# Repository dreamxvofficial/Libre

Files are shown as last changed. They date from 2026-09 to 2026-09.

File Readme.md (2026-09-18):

# Libre By DreamXV #
## It is an E-Ink Reading Device made for portability and mostly for warm-up week of *halflife.hackclub.com*. I have always been a fan of Kindle but its price is too high and it is not that customizable so I thought of making my own e-ink reader. ##
---
## Specs ##
- **Processor** ESP32-S3-WROOM-1-N16R8
- **Display** Waveshare 4.2", 400×300, B/W, SPI
- **Battery** 3.7 V Li-Po, 2000 mAh
- **MicroSD card**	16/32 GB 
- **USB-C** USB 2.0 Type-C receptacle
- **5 UI buttons** 6×6 × ~5 mm tactile push button
- **Power switch** SPDT slide switch

## Inspo Look ##
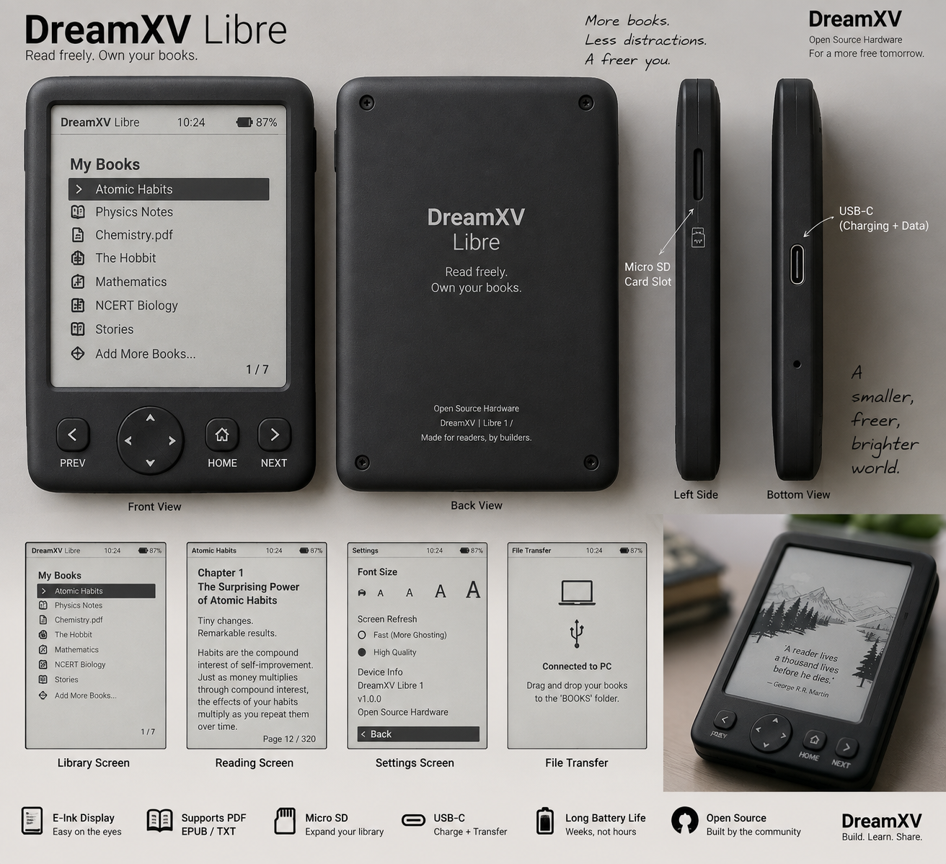
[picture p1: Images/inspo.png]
Inspo Look


## Approximate BOM : ##

| Part | Specification | Qty |
| --- | --- | --: |
| E-Ink Display | Waveshare 4.2" 400×300 B/W, SPI | 1 |
| Microcontroller | ESP32-S3-DevKitC-1-N16R8V | 1 |
| Storage | 16–32GB MicroSD Card + Socket | 1 |
| Battery | 3.7V 3000mAh Li-Po | 1 |
| Charging | MCP73831 Li-Po Charging Circuit | 1 |
| Power Switch | SPDT ON/OFF Slide Switch | 1 |
| Navigation | 6×6mm SMD Tactile Buttons | 5 |
| PCB | Custom 2-Layer PCB | 1 |
| Enclosure | Custom 3D-Printed Case | 1 |

## ** Approximate BOM ~ $110 or ~₹10,500 INR ** ##

## Schematic ##
### So i used AI for planing the connections of schematics and it just made me wanna die so yeah i dont know what to write more but i have connected the screen mcu micro sd and buttons together i dont know how but yes i have connected ###

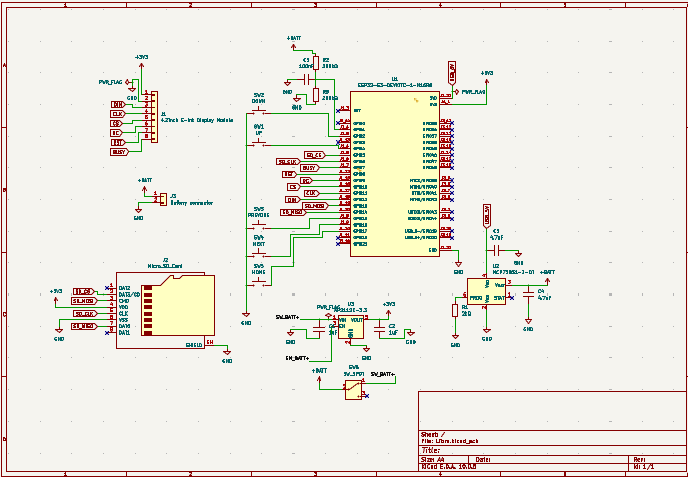
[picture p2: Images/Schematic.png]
Schematic


## PCB ## 
### I just wanna give up mannnnnnnnnnn! >>>>>>>>>>3 I had to change the whole design as PCB was not as size of CAD so here is the new PCB with MCU ESP 32, 5 buttons 1 slider button and Micro SD Card ##
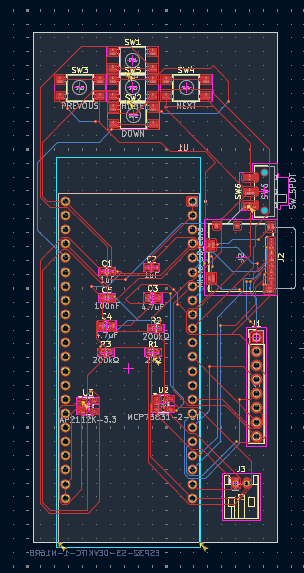
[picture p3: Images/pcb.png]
PCB

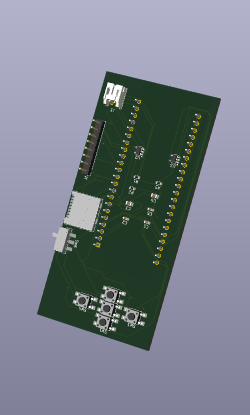
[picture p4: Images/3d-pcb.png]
3D PCB


## CAD ##
### CAD design for Libre. It is 130 mm height and 78.5 mm width with a space for PCB, Buttons and E-Ink Display ##

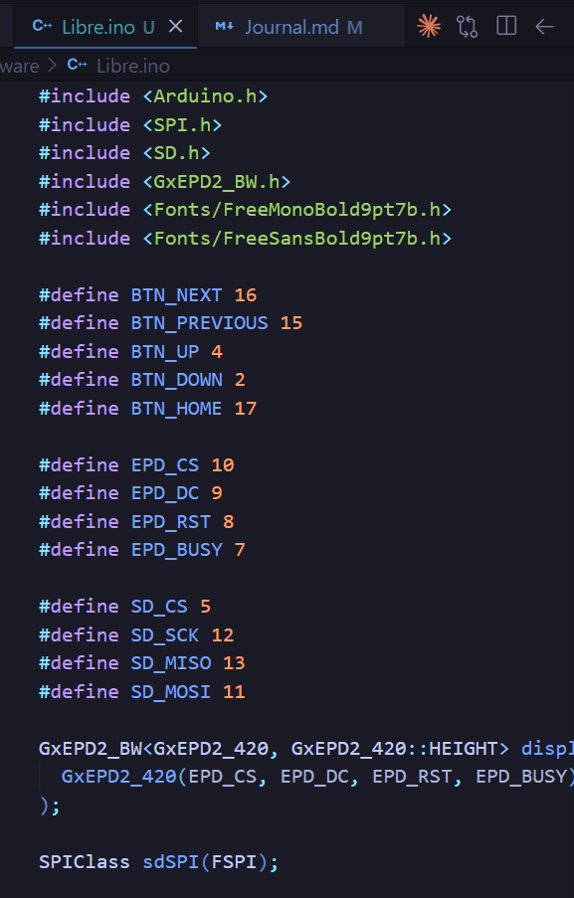
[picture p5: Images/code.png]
NewCAD


## Final BOM ##

# DreamXV Libre — Final BOM

| Part | Qty | Unit Price (INR) | Total (INR) | Price Basis | Design Ref |
|---|---:|---:|---:|---|---|
| Waveshare 4.2-inch E-Ink Module B, 400x300 | 1 | ₹4,861.00 | ₹4,861.00 | Amazon India / current listing checked | Main display |
| ESP32-S3-DEVKITC-1-N16R8V | 1 | ₹1,500.00 | ₹1,500.00 | Indian/Amazon market listing checked | Main MCU board |
| Li-Po battery 3.7V 3000mAh | 1 | ₹500.00 | ₹500.00 | Indian hobby-retailer budget | Battery |
| Custom PCB | 1 | ₹1,000.00 | ₹1,000.00 | User budget | PCB fabrication |
| 3D-printed enclosure | 1 | ₹960.00 | ₹960.00 | User budget: $10 | 3D printing |
| Molex 104031-0811 MicroSD socket | 1 | ₹100.00 | ₹100.00 | Indian distributor budget | J2 |
| JST-PH 2-pin battery connector | 1 | ₹40.00 | ₹40.00 | Indian hobby-retailer budget | J3 |
| 8-pin display connector/header | 1 | ₹50.00 | ₹50.00 | Indian hobby-retailer budget | J1 |
| MCP73831-2-OT Li-Po charger IC | 1 | ₹80.00 | ₹80.00 | Indian distributor budget | U2 |
| AP2112K-3.3 LDO | 1 | ₹50.00 | ₹50.00 | Indian distributor budget | U3 |
| TL3305AF160QG SMD tactile button | 5 | ₹48.00 | ₹240.00 | Robu India listing | SW1-SW5 |
| C&K JS102011SAQN SPDT SMD switch | 1 | ₹150.00 | ₹150.00 | Indian distributor budget | SW6 |
| 1uF 0805 MLCC | 2 | ₹10.00 | ₹20.00 | Robu India example | C1-C2 |
| 4.7uF MLCC | 2 | ₹15.00 | ₹30.00 | Indian distributor budget | C3-C4 |
| 100nF 0805 MLCC | 1 | ₹3.00 | ₹3.00 | Indian distributor budget | C5 |
| 2kΩ 0805 resistor | 1 | ₹2.00 | ₹2.00 | Indian distributor budget | R1 |
| 200kΩ 0805 resistor | 2 | ₹0.31 | ₹0.62 | Robu India example | R2-R3 |

## Total Cost

- **Total INR:** ₹9,586.62
- **Exchange Rate:** ₹95.95 = $1
- **Total USD:** $99.91
- **Budget:** $100
- **Status:** UNDER $100

## Firmware ##

### ** The firmware is written for the ESP32-S3 and handles the main functions of Libre like the E-Ink display, MicroSD card, 5 navigation buttons and battery monitoring. It also has a simple file browser for selecting books and basic TXT reading. PDF files can be detected and listed, with proper PDF rendering planned for a future version. ** ###

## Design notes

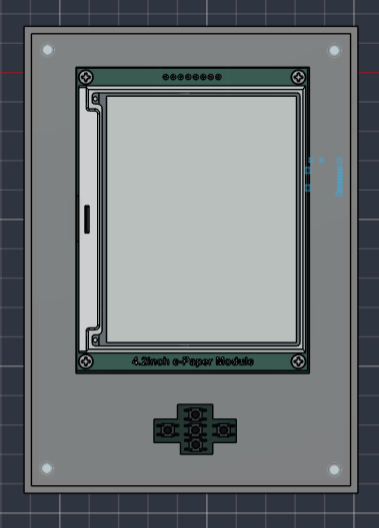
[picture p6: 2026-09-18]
Images/NewCAD.png

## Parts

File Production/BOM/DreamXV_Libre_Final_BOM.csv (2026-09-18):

Part | Specification | Qty | Total Price INR
E-Ink Display | Waveshare 4.2 inch, 400x300, SPI | 1 | 4861.18
MCU | ESP32-S3-DevKitC-1-N16R8V | 1 | 1500.00
Battery | 3.7V 3000mAh Li-Po | 1 | 469.00
Custom PCB | 2-layer PCB | 1 | 1000.00
3D Printed Enclosure | Custom CAD enclosure | 1 | 1920.00
MicroSD Socket | Molex 104031-0811 | 1 | 100.00
JST Battery Connector | JST-PH 2-pin | 1 | 40.00
Display Header | 1x8, 2.54mm | 1 | 50.00
Li-Po Charger | MCP73831-2-OT | 1 | 80.00
3.3V LDO | AP2112K-3.3 | 1 | 50.00
Navigation Buttons | 6x6mm SMD tactile | 5 | 240.00
Power Switch | C&K JS102011SAQN SPDT | 1 | 115.00
1uF Capacitors | 0805 MLCC | 2 | 20.00
4.7uF Capacitors | MLCC | 2 | 30.00
100nF Capacitor | 0805 | 1 | 3.00
2kΩ Resistor | 0805 | 1 | 2.00
200kΩ Resistors | 0805 | 2 | 0.62
TOTAL

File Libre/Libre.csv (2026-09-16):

Reference | Qty | Value | DNP | Exclude from BOM | Exclude from Board | Exclude from Simulation | Exclude from Position Files | Footprint | Datasheet
C1,C2 | 2 | 1uF |  |  |  |  | ${EXCLUDE_FROM_POS_FILES} | Capacitor_SMD:C_0603_1608Metric
C3,C4 | 2 | 4.7uF |  |  |  |  | ${EXCLUDE_FROM_POS_FILES} | Capacitor_SMD:C_0805_2012Metric
C5 | 1 | 100nF |  |  |  |  | ${EXCLUDE_FROM_POS_FILES} | Capacitor_SMD:C_0603_1608Metric
J1 | 1 | 4.2inch E-Ink Display Module |  |  |  |  | ${EXCLUDE_FROM_POS_FILES} | Connector_PinHeader_2.54mm:PinHeader_1x08_P2.54mm_Vertical
J2 | 1 | Micro_SD_Card |  |  |  |  | ${EXCLUDE_FROM_POS_FILES} | Connector_Card:microSD_HC_Molex_104031-0811 | https://www.we-online.com/components/products/datasheet/693072010801.pdf
J3 | 1 | Battery connector |  |  |  |  | ${EXCLUDE_FROM_POS_FILES} | Connector_JST:JST_PH_S2B-PH-K_1x02_P2.00mm_Horizontal
R1 | 1 | 2kΩ |  |  |  |  | ${EXCLUDE_FROM_POS_FILES} | Resistor_SMD:R_0603_1608Metric
R2,R3 | 2 | 200kΩ |  |  |  |  | ${EXCLUDE_FROM_POS_FILES} | Resistor_SMD:R_0603_1608Metric
SW1 | 1 | UP |  |  |  |  | ${EXCLUDE_FROM_POS_FILES} | Button_Switch_SMD:SW_SPST_TL3305A
SW2 | 1 | DOWN |  |  |  |  | ${EXCLUDE_FROM_POS_FILES} | Button_Switch_SMD:SW_SPST_TL3305A
SW3 | 1 | PREVOUS |  |  |  |  | ${EXCLUDE_FROM_POS_FILES} | Button_Switch_SMD:SW_SPST_TL3305A
SW4 | 1 | NEXT |  |  |  |  | ${EXCLUDE_FROM_POS_FILES} | Button_Switch_SMD:SW_SPST_TL3305A
SW5 | 1 | HOME |  |  |  |  | ${EXCLUDE_FROM_POS_FILES} | Button_Switch_SMD:SW_SPST_TL3305A
SW6 | 1 | SW_SPDT |  |  |  |  | ${EXCLUDE_FROM_POS_FILES} | Button_Switch_SMD:SW_SPDT_CK_JS102011SAQN
U1 | 1 | ESP32-S3-DEVKITC-1-N16R8 |  |  |  |  | ${EXCLUDE_FROM_POS_FILES} | Esp:XCVR_ESP32-S3-DEVKITC-1-N16R8V
U2 | 1 | MCP73831-2-OT |  |  |  |  | ${EXCLUDE_FROM_POS_FILES} | Package_TO_SOT_SMD:SOT-23-5 | http://ww1.microchip.com/downloads/en/DeviceDoc/20001984g.pdf
U3 | 1 | AP2112K-3.3 |  |  |  |  | ${EXCLUDE_FROM_POS_FILES} | Package_TO_SOT_SMD:SOT-23-5 | https://www.diodes.com/assets/Datasheets/AP2112.pdf

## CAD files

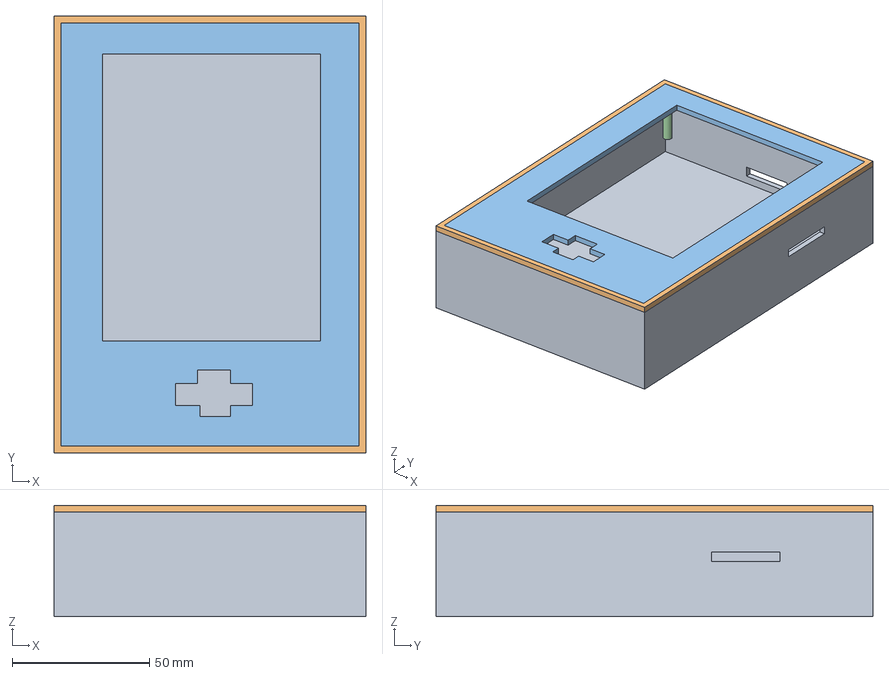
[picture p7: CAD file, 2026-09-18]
Production/CAD_Case/Libre_PCB_Assembly.step
113.5 x 159.0 x 40.5 mm

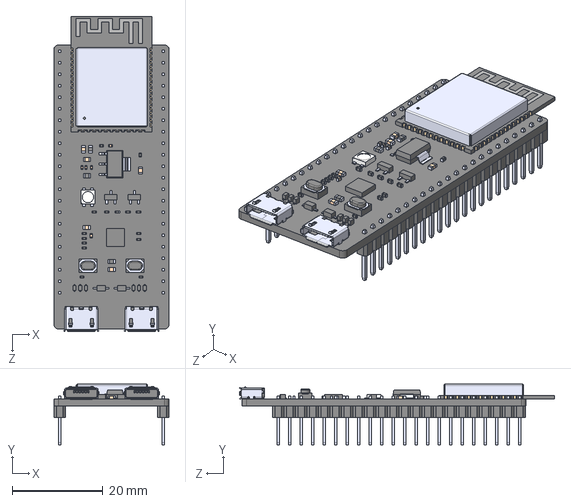
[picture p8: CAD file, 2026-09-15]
Additional Models and Schematics/ESP32-S3-DEVKITC-1-N16R8V/ESP32-S3-DEVKITC-1-N16R8V.step
25.4 x 13.4 x 69.6 mm

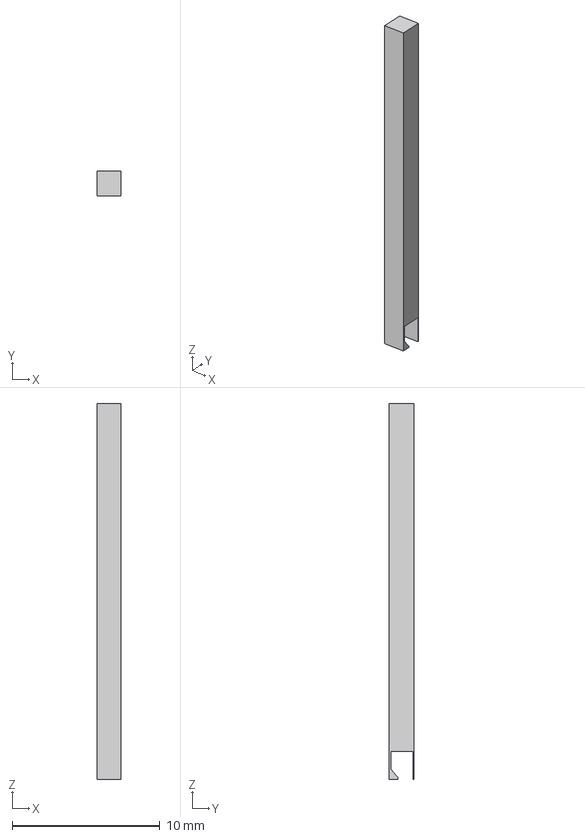
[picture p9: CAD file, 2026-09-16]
Additional Models and Schematics/Slider Cap.step
1.65 x 1.70 x 25.4 mm

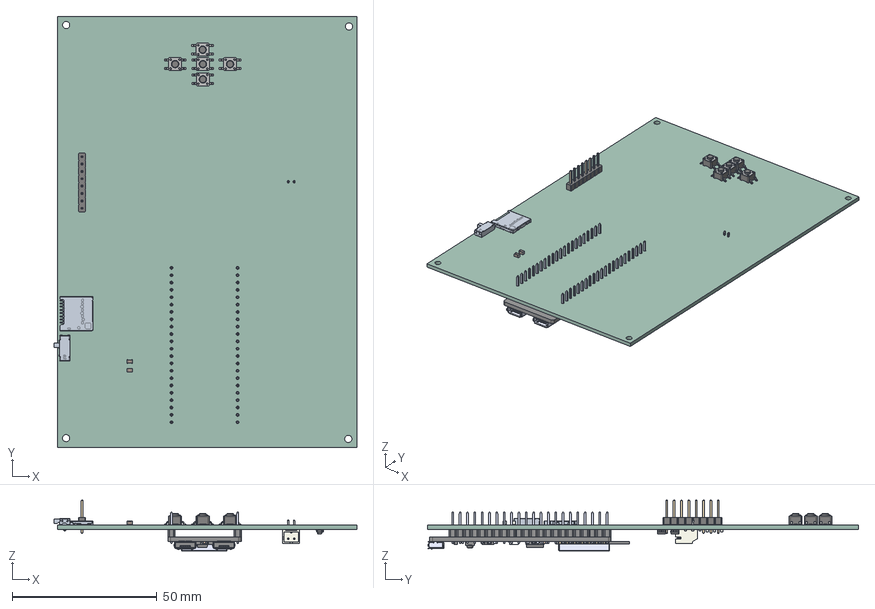
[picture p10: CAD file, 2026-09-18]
Libre/Libre.step
104.7 x 149.0 x 17.6 mm
SW_SPST_TL3305A x 5
C_0805_2012Metric x 2
PinHeader_1x08_P254mm_Vertical
JS102011SAQN_SW0004_PRT
ESP32-S3-DEVKITC-1-N8R2
SOT-23-5 x 2
C_0603_1608Metric x 3
R_0603_1608Metric x 3
JST_S2B_PH_K
Libre_PCB

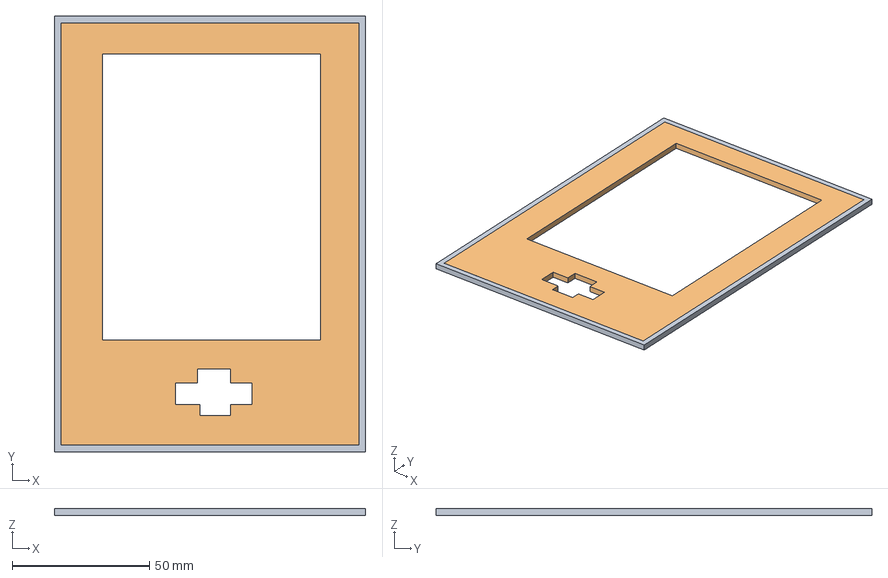
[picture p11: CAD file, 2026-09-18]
Production/CAD_Case/Libre_PCB_Lid.step
113.5 x 159.0 x 2.50 mm

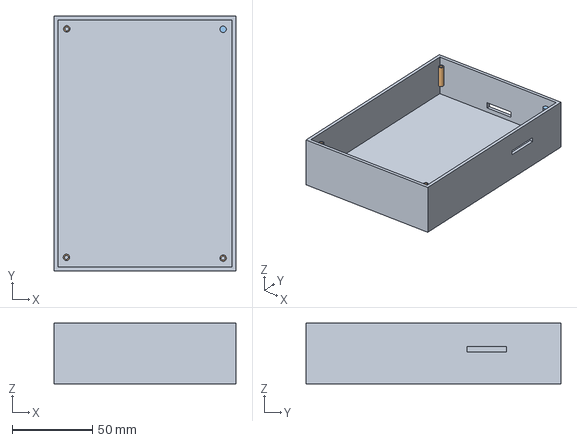
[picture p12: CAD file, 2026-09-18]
Production/CAD_Case/Libre_PCB_Base.step
113.5 x 159.0 x 38.0 mm

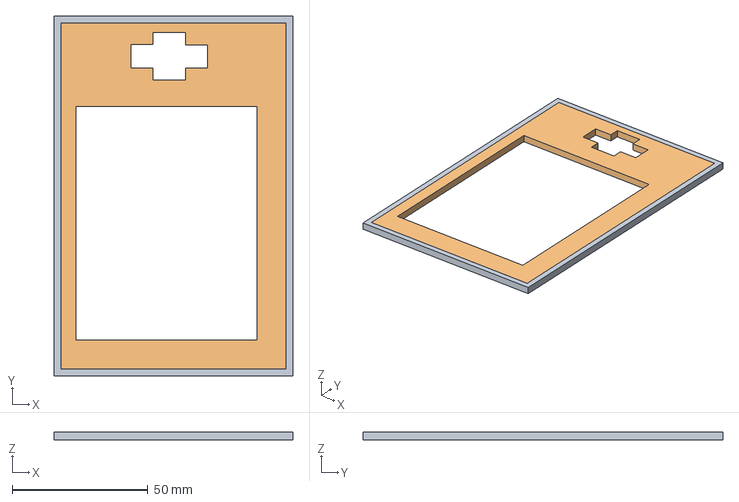
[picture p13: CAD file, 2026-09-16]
Production/CAD_Case/Libre_LID.step
87.8 x 132.5 x 3.00 mm

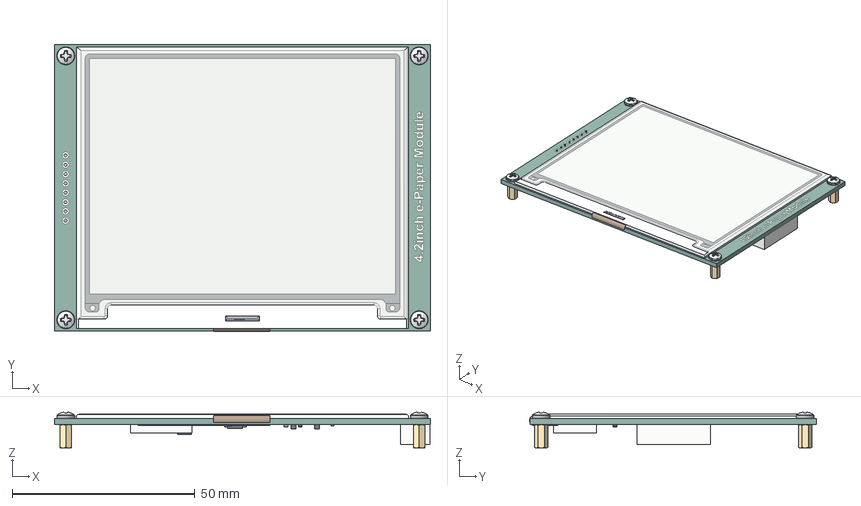
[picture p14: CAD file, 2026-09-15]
Additional Models and Schematics/Waveshare 4.2inch e-Paper Module.step
103.0 x 78.6 x 9.79 mm
Waveshare 4.2 E-Ink - Display folded cable
PCB
90268A201 x 4
91772A030 x 4

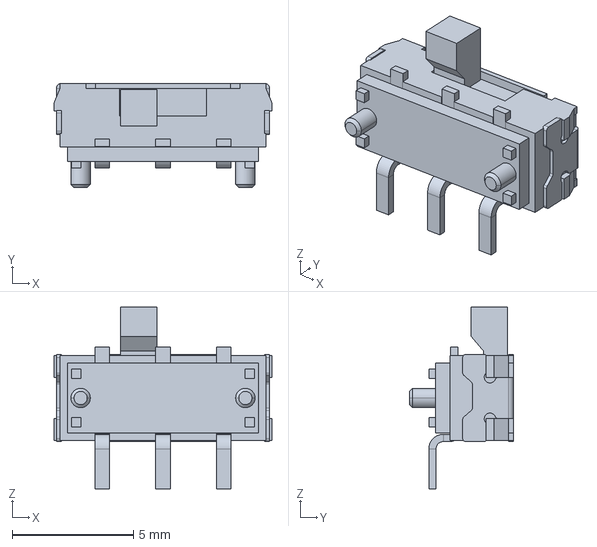
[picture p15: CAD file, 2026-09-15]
Additional Models and Schematics/JS102011SAQN.step
9.00 x 4.30 x 7.50 mm

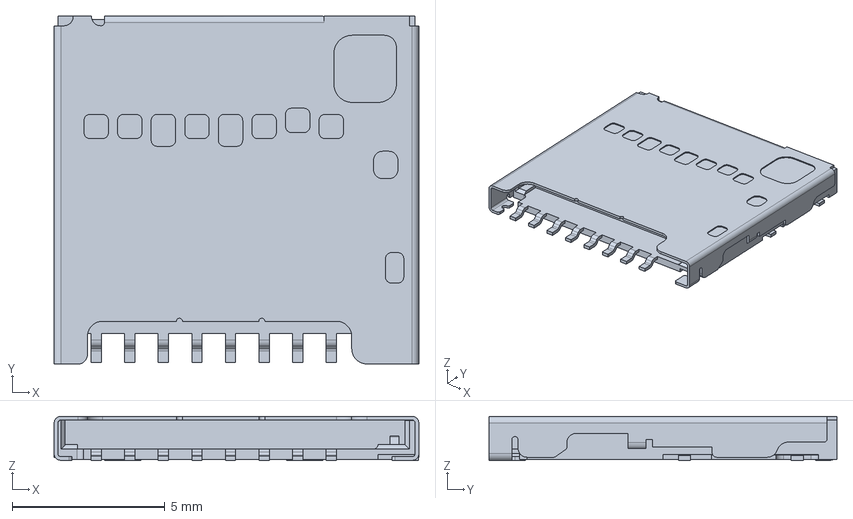
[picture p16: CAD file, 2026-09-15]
Additional Models and Schematics/1040310811.stp
11.9 x 11.4 x 1.45 mm

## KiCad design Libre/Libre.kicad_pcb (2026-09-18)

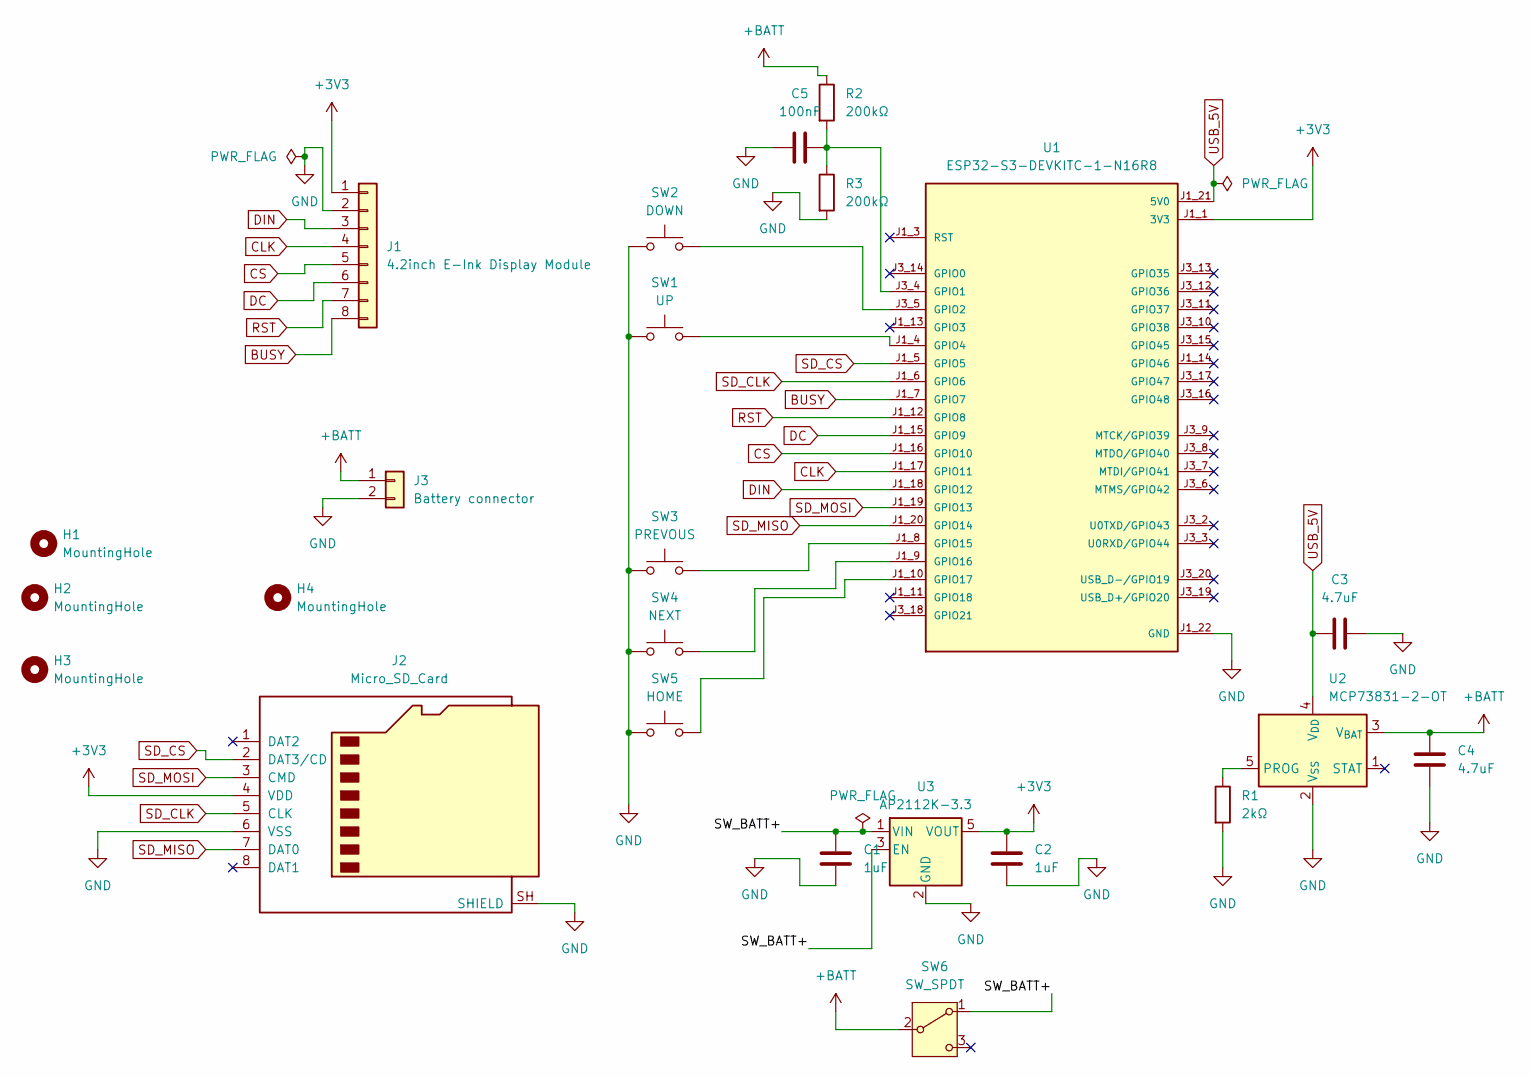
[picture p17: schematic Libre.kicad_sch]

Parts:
C1, C2: 1uF; C_0603_1608Metric
C3, C4: 4.7uF; C_0805_2012Metric
C5: 100nF; C_0603_1608Metric
H1, H2, H3, H4: MountingHole; MountingHole_2.5mm
J1: 4.2inch E-Ink Display Module; PinHeader_1x08_P2.54mm_Vertical
J2: Micro_SD_Card; microSD_HC_Molex_104031-0811
J3: Battery connector; JST_PH_S2B-PH-K_1x02_P2.00mm_Horizontal
R1: 2kΩ; R_0603_1608Metric
R2, R3: 200kΩ; R_0603_1608Metric
SW1: UP; SW_SPST_TL3305A
SW2: DOWN; SW_SPST_TL3305A
SW3: PREVOUS; SW_SPST_TL3305A
SW4: NEXT; SW_SPST_TL3305A
SW5: HOME; SW_SPST_TL3305A
SW6: SW_SPDT; SW_SPDT_CK_JS102011SAQN
U1: ESP32-S3-DEVKITC-1-N16R8; XCVR_ESP32-S3-DEVKITC-1-N16R8V; PARTREV V1
U2: MCP73831-2-OT; SOT-23-5
U3: AP2112K-3.3; SOT-23-5

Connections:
+3V3: C2.1, J1.1, J2.4 (VDD), U1.J1_1 (3V3), U1.J1_2 (3V3), U3.5 (VOUT)
+BATT: C4.1, J3.1, R2.1, SW6.2 (B), U2.3 (V_{BAT})
/SW_BATT+: C1.1, SW6.1 (A), U3.1 (VIN), U3.3 (EN)
BUSY: J1.8, U1.J1_7 (GPIO7)
CLK: J1.4, U1.J1_17 (GPIO11)
CS: J1.5, U1.J1_16 (GPIO10)
DC: J1.6, U1.J1_15 (GPIO9)
DIN: J1.3, U1.J1_18 (GPIO12)
GND: C1.2, C2.2, C3.2, C4.2, C5.1, J1.2, J2.6 (VSS), J2.SH (SHIELD), J3.2, R1.2, R3.2, SW1.1, SW2.1, SW3.1, SW4.1, SW5.1, U1.J1_22 (GND), U1.J3_1 (GND), U1.J3_21 (GND), U1.J3_22 (GND), U2.2 (V_{SS}), U3.2 (GND)
unnamed: C5.2, R2.2, R3.1, U1.J3_4 (GPIO1)
unnamed: SW2.2, U1.J3_5 (GPIO2)
unnamed: SW1.2, U1.J1_4 (GPIO4)
unnamed: SW3.2, U1.J1_8 (GPIO15)
unnamed: SW4.2, U1.J1_9 (GPIO16)
unnamed: SW5.2, U1.J1_10 (GPIO17)
unnamed: R1.1, U2.5 (PROG)
RST: J1.7, U1.J1_12 (GPIO8)
SD_CLK: J2.5 (CLK), U1.J1_6 (GPIO6)
SD_CS: J2.2 (DAT3/CD), U1.J1_5 (GPIO5)
SD_MISO: J2.7 (DAT0), U1.J1_20 (GPIO14)
SD_MOSI: J2.3 (CMD), U1.J1_19 (GPIO13)
USB_5V: C3.1, U1.J1_21 (5V0), U2.4 (V_{DD})

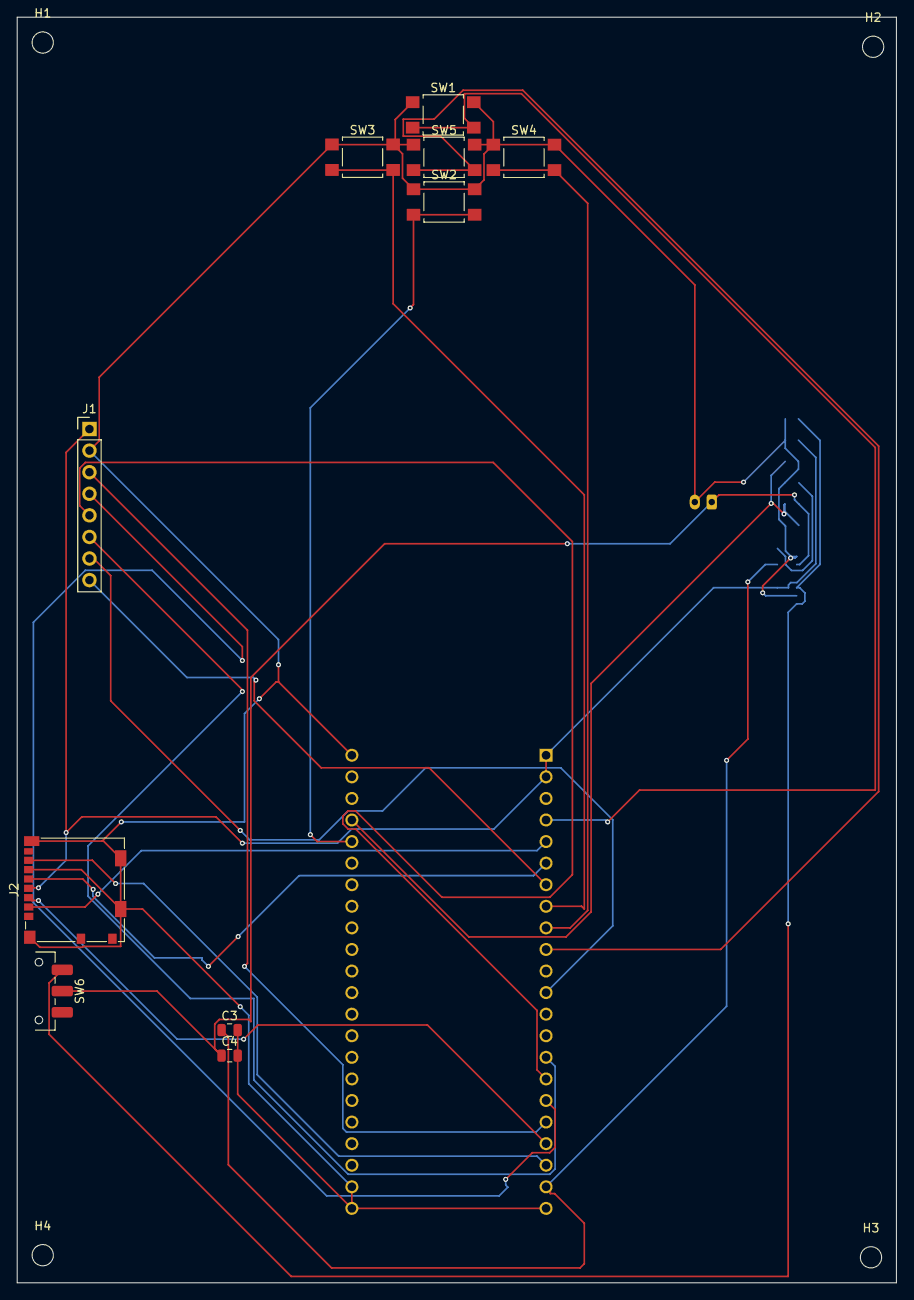
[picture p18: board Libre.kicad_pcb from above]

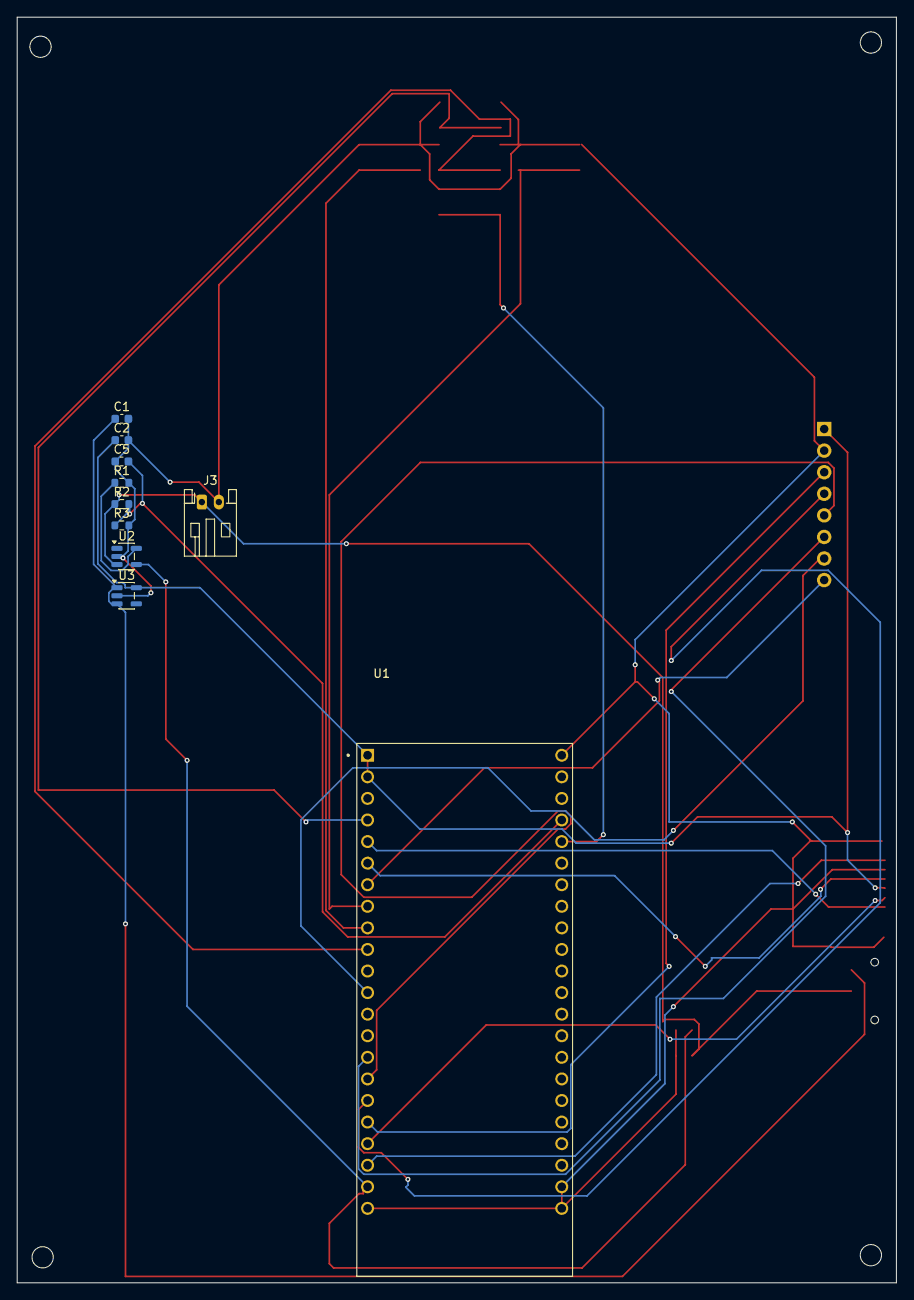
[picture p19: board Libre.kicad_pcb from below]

Board: 2 copper layers, 103.5 x 149.0 mm, 24 parts (10 on the bottom side), 22 nets.

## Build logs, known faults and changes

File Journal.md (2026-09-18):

# Libre by DreamXV #
## I will be documenting this project in journal as well as lapse and hacktime##
---
## Day 1 - 14 sept 26 ##
### So from today warm-up wek started and i thought of making a e-ink reader for myself which i can use for reading like PDFs, ePUBs, Webtoons and other reading material. My main inspo is the amazon kindle so I have planned the following features for my reader:
- E-ink display
- Next Page Button
- Previous Page Button
- Up Button
- Down Button 
- And at last Home Button 

* Inspo Look of how it would look like *

Inspo Look

## Hardware ## 
### for now i have finalized the hardware list and it is available in Readme.md ### 

## For today i am only journaling as it is much of a brainstorming phase and i am yet to build Schematic PCB or CAD ##

## Time spent this session: 1 hour ##

---

## Day 2 - 15 sept 26 ##
## Session-1 ##
### So In this session I will be working on building schematic for Libre. So i used AI to help me make schematics and find sch and mod files for symbols and footprint. SO it took so much time and effort of mine to check and connect each gpio and pin properly. I also added micro sd card slot and all. Now going for lunch break.### 

Schematic
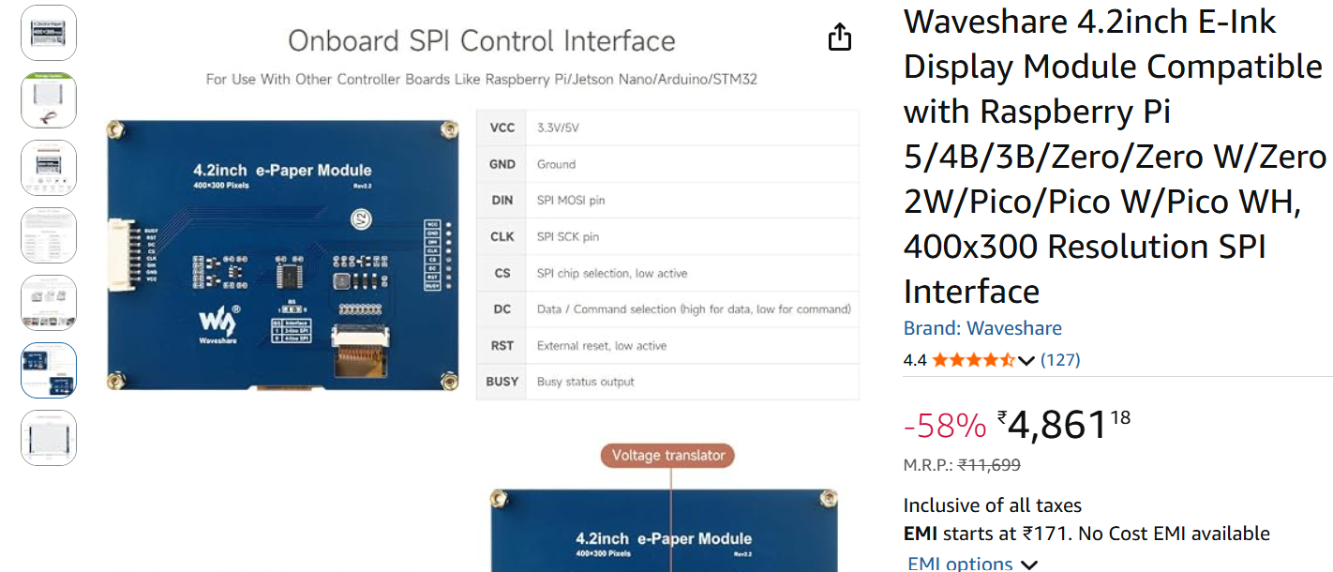
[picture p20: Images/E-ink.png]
Amazon Screen


## Time spent this session: 1 hour 40 mins  ##

## Day 2 - 15 sept 26 ##
## Session-2 ##
### So In this session I will be working on PCB design for Libre. It was hell lot worse then schematic to find step models and designing PCB according to display was nightmare. But finally I made it!... I just want to thank god to give me strength from making this pcb as i would have left the chat gng :3 .... Here i present you PCB ###
PCB
3D PCB

## Time spent this session: 2 Hours ##

## Day 2 - 15 sept 26 ##
## Session-3 ##
### So In this session I will be working on CAD design for Libre. It was the biggest mistake i made ever and because of it i had to make button and slider buttons extras so that it could be outside the frame to use but it turned out good for reading so now i present you CAD Design ### 

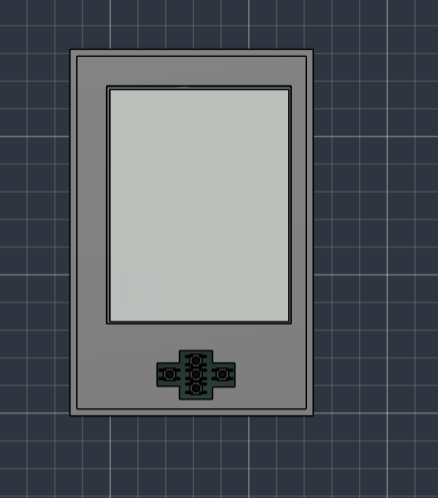
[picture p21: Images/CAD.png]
CAD


## Time spent this session: 1 Hour 56 Minutes ##

## Day 3 - 16 sept 26 ##
## Session-1 ##
### So In this session made final touches of cad design for button and it turned out good so here is the extra part for mounting buttons and slider ### 

Button Mount
Slider Mount

## Time spent this session: 12 Minutes ##

## Day 3 - 16 sept 26 ##
## Session-2 ##
### So In this session i wrote the firmware for Libre. So i wrote an os type system for it to select the pdf of the book in and read it . It was hell lot of fun and also challenging to write it as it was my first time writing firmware for an e-reader. But due to my C++ skill i coded it a lot faster. Butt i want to add more featuresas they are left. ### 

code

## Time spent this session: 43 Minutes ##

## Day 4 - 17 sept 26 ##
## Session-1 ##
### So In this session i remade the CAD as there were problems with previous CAD and had to make buttons caps as another thing but this time i fixed the pcb and made nice looking CAD and this would be the last journaling i think ##

PCB

## Time spent this session: 1hour 34 Minutes ##

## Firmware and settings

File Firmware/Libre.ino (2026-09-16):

#include <Arduino.h>
#include <SPI.h>
#include <SD.h>
#include <GxEPD2_BW.h>
#include <Fonts/FreeMonoBold9pt7b.h>
#include <Fonts/FreeSansBold9pt7b.h>

#define BTN_NEXT 16
#define BTN_PREVIOUS 15
#define BTN_UP 4
#define BTN_DOWN 2
#define BTN_HOME 17

#define EPD_CS 10
#define EPD_DC 9
#define EPD_RST 8
#define EPD_BUSY 7

#define SD_CS 5
#define SD_SCK 12
#define SD_MISO 13
#define SD_MOSI 11

GxEPD2_BW<GxEPD2_420, GxEPD2_420::HEIGHT> display(
  GxEPD2_420(EPD_CS, EPD_DC, EPD_RST, EPD_BUSY)
);

SPIClass sdSPI(FSPI);

struct Button {
    unit8_t pin;
    bool lastState;
};

Button buttons[] = {
    {BTN_NEXT, true},
    {BTN_PREVIOUS, true},
    {BTN_UP, true},
    {BTN_DOWN, true},
    {BTN_HOME, true},
};

enum ButtonEvent {
    NONE,
    NEXT,
    PREVIOUS,
    UP,
    DOWN,
    HOME,
};

ButtonEvent readButton(){
    const uint8_t pins[] = {
        BTN_UP, BTN_DOWN, BTN_HOME, BTN_NEXT, BTN_PREVIOUS
    };

    for (int i=0; i<5; i++){
        bool state = digitalRead(pins[i]);
         if (state == LOW && buttons[i].lastState == HIGH) {
      delay(25);
      if (digitalRead(pins[i]) == LOW) {
        buttons[i].lastState = LOW;
        return (ButtonEvent)(i + 1);
      }
    }
    if (state == HIGH) {
      buttons[i].lastState = HIGH;
    }
  }
  return NONE;
}

const int MAX_BOOKS = 100;
String books[MAX_BOOKS];
int bookCount = 0;
int selectedBook = 0;

bool isBookFile(const String &name) {
    String lower = name;
    lower.toLowerCase()

    return lower.endsWith(".pdf") ||
           lower.endsWith(".epub") ||
           lower.endsWith(".txt");
           lower.endsWith(".text");
}

void scanBooks() {
    bookCount = 0;

    File root = SD.open("/" );
    if (!root){
        return;
    }
    File file = root.openNextFile();

    while(file && bookCount < MAX_BOOKS) {
        if(file.isDirectory()){
            String name = String(file.name());
            
            if (isBookFile(name)){
                books[bookCount++] = name;
            }
        }  
      file.close();
      file = root.openNextFile();
    }
    root.close();

  if (selectedBook >= bookCount) {
    selectedBook = max(0, bookCount - 1);
  }
}

float readButtonVoltage(){
    const float ADC_REFERENCE = 3.3f;
    const float DIVIDER_RATIO = 2.0f;

    unit16_t raw = analogRead(BATTERY_ADC);
    float vadc = (raw / 4095.0f) * ADC_REFERENCE;
    return vadc * DIVIDER_RATIO;
}

int batteryPercent(float voltage){

  if (voltage >= 4.20) return 100;
  if (voltage >= 4.10) return 90;
  if (voltage >= 4.00) return 75;
  if (voltage >= 3.90) return 60;
  if (voltage >= 3.80) return 45;
  if (voltage >= 3.70) return 30;
  if (voltage >= 3.60) return 15;
  if (voltage >= 3.50) return 5;
  return 0;
}

void drawHeader(const char *title){
  display.setFont(&FreeMonoBold9pt7b);
  display.setTextColor(GxEPD_BLACK);
  display.setCursor(8, 20);
  display.print(title);

  display.drawLine(5, 27, display.width() - 5, 27, GxEPD_BLACK);
}

void drawBattery(){
    float v = readBatteryVoltage();
    int p = batteryPercent(v);

    String text = String(p)+"%";
    display.setFont(&FreeMonoBold19pt7b);
    display.setTextColor(GxEPD_BLACK);
    display.setCursor(display.width() - 55, 20);
    display.print(text);
}

void showMessage(const String &line1, const String &line2 = ""){
    display.setFullWindow();
    display.firstPage();
    do {
        display.fillScreen(GxEPD_WHITE);

        display.setFont(&FreeSansBold12pt7b);
        display.setTextColor(GxEPD_BLACK);
        display.setCursor(10, 40);
        display.print(line1);

        if (line2.length()) {
            display.setCursor(10, 65);
            display.print(line2);
        }
    } while (display.nextPage());
}

void drawLibrary(){
    display.setFullWindow();
    display.firstPage();

    do{
        display.fillScreen(GxEPD_WHITE);

        drawHeader("DREAMXV LIBRE");
        drawBattery();

        if (bookCount == 0) {
            display.setFont(&FreeMonoBold9pt7b);
            display.setCursor(10, 65);
            display.print("No books found.");
            display.setCursor(10, 90);
            display.print("Copy PDF/TXT to MicroSD.");
        } else {
            display.setFont(&FreeMonoBold9pt7b);

            int start = max(0, selectedBook - 4);
            int end = min(bookCount, start + 8);

            for (int i = start; i < end; i++) {
                int y = 50 + ((i - start) * 28);

                if (i == selectedBook) {
                    display.fillRect(5, y - 17, display.width() - 10, 23, GxEPD_BLACK);
                    display.setTextColor(GxEPD_WHITE);
                } else {
                    display.setTextColor(GxEPD_BLACK);
                }

                String name = books[i];
                if (name.length() > 37) {
                    name = name.substring(0, 34) + "...";
                }
                
                display.setCursor(10, y);
                display.print(name);
            }
        }
    } while (display.nextPage());
}

void showTextPage(File &file, uint32_t startPosition) {
  const int linesPerPage = 16;
  const int charsPerLine = 48;

  file.seek(startPosition);

  String lines[linesPerPage];
  int lineCount = 0;

  while (file.available() && lineCount < linesPerPage) {
    String line = file.readStringUntil('\n');
    line.replace("\r", "");

    while (line.length() > 0 && lineCount < linesPerPage) {
      if (line.length() <= charsPerLine) {
        lines[lineCount++] = line;
        line = "";
      } else {
        lines[lineCount++] = line.substring(0, charsPerLine);
        line = line.substring(charsPerLine);
      }
    }
  }

  display.setFullWindow();
  display.firstPage();

  do {
    display.fillScreen(GxEPD_WHITE);
    display.setFont(&FreeMonoBold9pt7b);
    display.setTextColor(GxEPD_BLACK);

    for (int i = 0; i < lineCount; i++) {
      display.setCursor(5, 20 + (i * 18));
      display.print(lines[i]);
    }
  } while (display.nextPage());
}

void readTextBook(const String &path) {
  File file = SD.open(path, FILE_READ);

  if (!file) {
    showMessage("Cannot open file");
    delay(1000);
    return;
  }

  uint32_t position = 0;

  showTextPage(file, position);

  while (true) {
    ButtonEvent event = readButton();

    if (event == HOME || event == PREVIOUS) {
      break;
    }

    if (event == NEXT) {
      if (position + 1 < file.size()) {

        position += 700;
        if (position >= file.size()) {
          position = file.size() > 700 ? file.size() - 700 : 0;
        }
        showTextPage(file, position);
      }
    }

    if (event == UP) {
      if (position >= 700) {
        position -= 700;
        showTextPage(file, position);
      }
    }

    delay(10);
  }

  file.close();
}

void renderPdfPage(const String &path, int pageNumber) {

  showMessage("PDF selected:", path);
  delay(1500);
  showMessage("PDF renderer", "not installed");
  delay(1500);
}

void openBook() {
  if (bookCount == 0) return;

  String path = books[selectedBook];
  String lower = path;
  lower.toLowerCase();

  if (lower.endsWith(".txt") || lower.endsWith(".text")) {
    readTextBook(path);
  } else if (lower.endsWith(".pdf")) {
    renderPdfPage(path, 1);
  }
}

void setup() {
  Serial.begin(115200);
  delay(500);

  pinMode(BTN_UP, INPUT_PULLUP);
  pinMode(BTN_DOWN, INPUT_PULLUP);
  pinMode(BTN_PREVIOUS, INPUT_PULLUP);
  pinMode(BTN_NEXT, INPUT_PULLUP);
  pinMode(BTN_HOME, INPUT_PULLUP);

  pinMode(BATTERY_ADC, INPUT);
  analogReadResolution(12);

  display.init(115200);
  display.setRotation(1);

  showMessage("DREAMXV LIBRE", "Starting...");
  delay(800);

  sdSPI.begin(SD_SCK, SD_MISO, SD_MOSI, SD_CS);

  if (!SD.begin(SD_CS, sdSPI)) {
    showMessage("MicroSD error", "Check card/wiring");
    delay(1500);
  } else {
    scanBooks();
  }

  drawLibrary();
}

void loop() {
  ButtonEvent event = readButton();

  switch (event) {
    case UP:
      if (bookCount > 0) {
        selectedBook--;
        if (selectedBook < 0) {
          selectedBook = bookCount - 1;
        }
        drawLibrary();
      }
      break;

    case DOWN:
      if (bookCount > 0) {
        selectedBook++;
        if (selectedBook >= bookCount) {
          selectedBook = 0;
        }
        drawLibrary();
      }
      break;

    case NEXT:
      openBook();
      drawLibrary();
      break;

    case PREVIOUS:

      scanBooks();
      drawLibrary();
      break;

    case HOME:
      scanBooks();
      selectedBook = 0;
      drawLibrary();
      break;

    case NONE:
      break;
  }

  delay(10);
}

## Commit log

2026-09-15 Day 2
    [1040310811.stp, ESP32-S3-DEVKITC-1-N16R8V.STEP, ESP32-S3-DEVKITC-1-N16R8V.step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]
2026-09-16 Day 3
    [DreamXV_Libre_Final_BOM.csv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]
2026-09-18 CAD Change
    [Libre-B_Cu.gbr, Libre-B_Mask.gbr, Libre-B_Paste.gbr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]
2026-09-18 BOM Updation
    [DreamXV_Libre_Final_BOM.csv]
